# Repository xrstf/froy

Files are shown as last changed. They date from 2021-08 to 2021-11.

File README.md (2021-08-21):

# Frøy - ESP8266+BME Hygrometer

This repository contains the source code, schematics and everything else for my
personal fancy homegrown hygrometer (sensor that reports temperature, humidity and
pressure).

## Features

* push or pull mode
* supports BME280, BME680 and BMP280 chips
* programming via USB (only for indoor variant, others need a standalone USB->UART converter)
* webserver with Prometheus compatible `/metrics` endpoint
* reconfiguration via USB or WiFi (i.e. `curl -XPOST -d'{"new":"config"}' http://device/`)
* OTA pull support (Frøy pulls new firmware from a specified location)
* TLS support (single fingerprint only)
* relatively easy to solder by hand (nothing smaller than an 0805 package)

## Mode of Operation

Both indoor and outdoor versions can work in one of two modes:

* **Pull Mode** ("server mode") -- in this mode, Frøy is constantly running and connected
  to your WiFi. It provides an HTTP server and expects you to fetch the data whenever
  you need it (for example via Prometheus).
* **Push Mode** -- in this mode, Frøy will make a measurement, connect to WiFi, send out the
  data to a preconfigured URL and then go to sleep for a configurable amount of time. Rinse
  and repeat.

The advantage of the Pull Mode is that the interval can be centralled controlled (if you have
multiple devices). It also makes it easier to trigger an OTA, as Frøy is constantly listening
for requests.

The advantage of the Push Mode is that Frøy doesn't need any Firewall rules to be reachable
and it saves power (critical for the Outdoor version). Also, indoor versions in Pull Mode would
considerable heat up (an ESP8266 that is connected to WiFi can be 35-40°C) and skew the sensor
readings. So even for indoor versions it is advisable to use Push Mode instead.

While Frøy is not reachable in Push Mode (it never starts a webserver and you'd be pretty luck
to send a request to it the moment it wakes up and before it goes back to sleep), it is still
possible to reconfigurable Frøy remotely by putting the new configuration in the _response_ to
Frøy's push request.

## Flavors

Frøy currently comes in three flavors:

### Frøy Outdoor

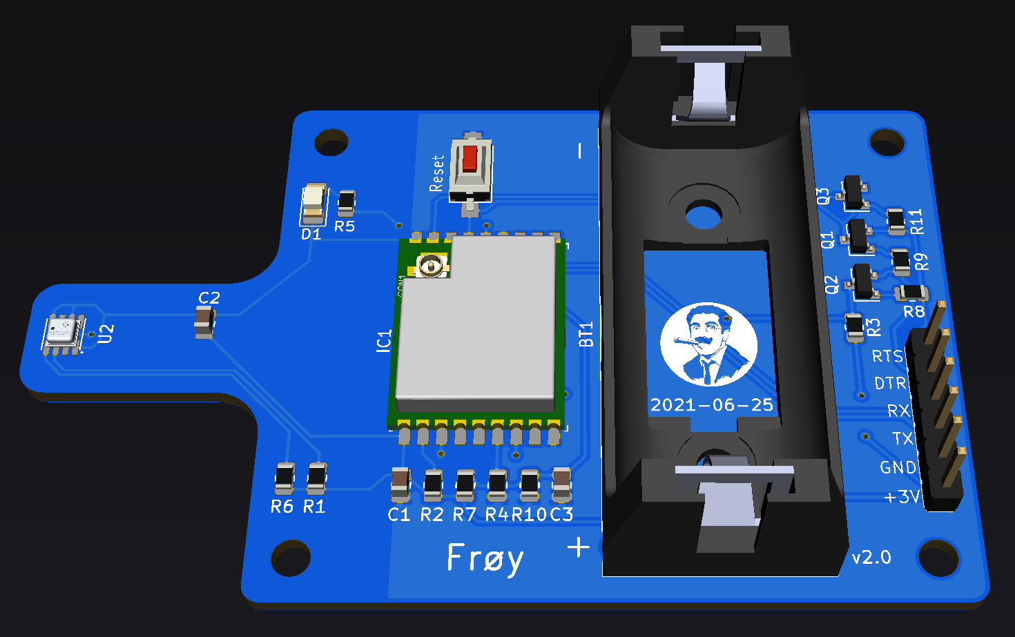
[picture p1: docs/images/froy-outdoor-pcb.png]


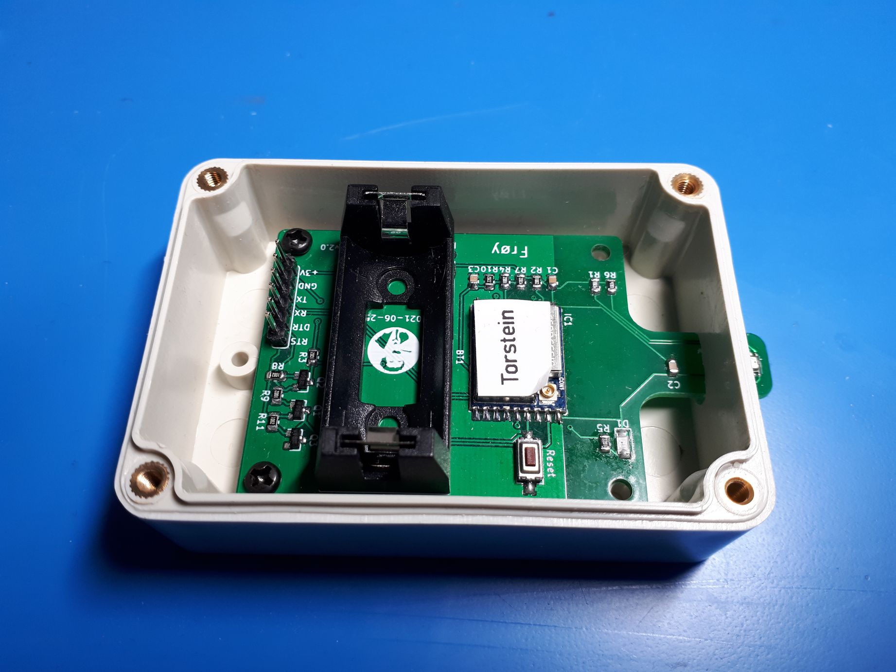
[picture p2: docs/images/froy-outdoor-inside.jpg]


This is the original project. It runs using a CR123 battery, which lasts roughly 3-5
months when reporting data every 15 minutes.

The case can be bought on Amazon: https://www.amazon.de/gp/product/B072M2JKGW/ -- I am not
aware of any alternative sources. In case the product disappears, I saved the schematics
in `docs/images/froy-outdoor-case-drawings.jpg`.

### Frøy Indoor

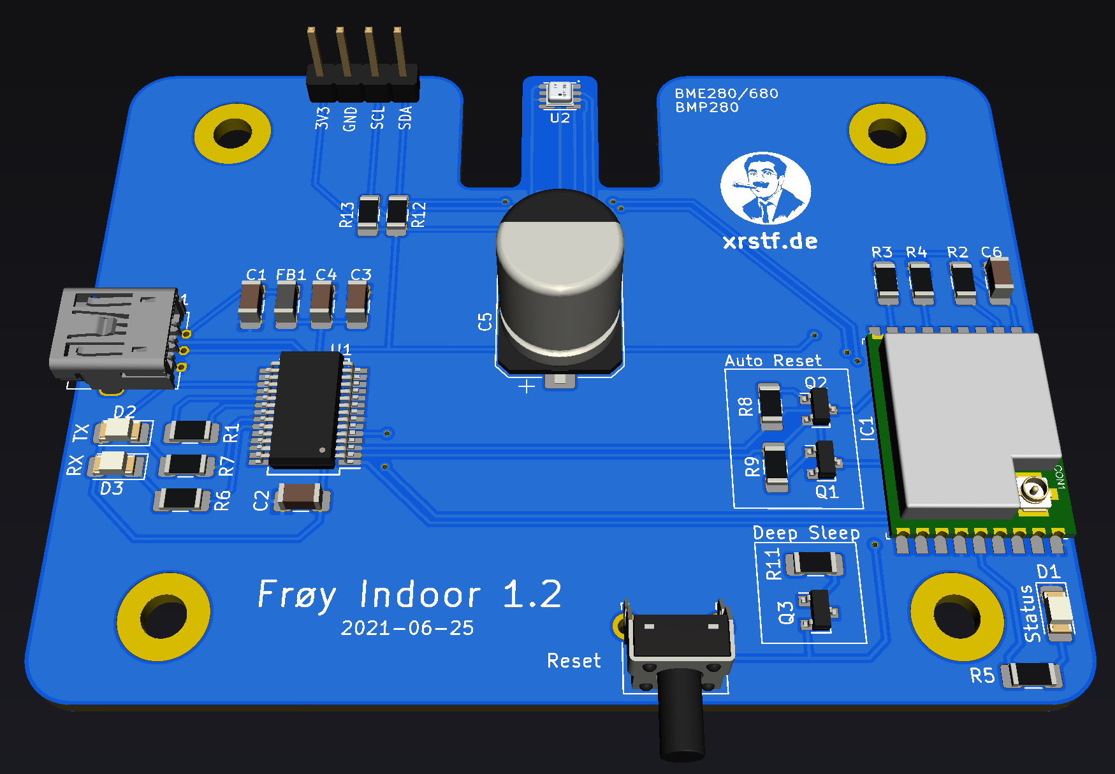
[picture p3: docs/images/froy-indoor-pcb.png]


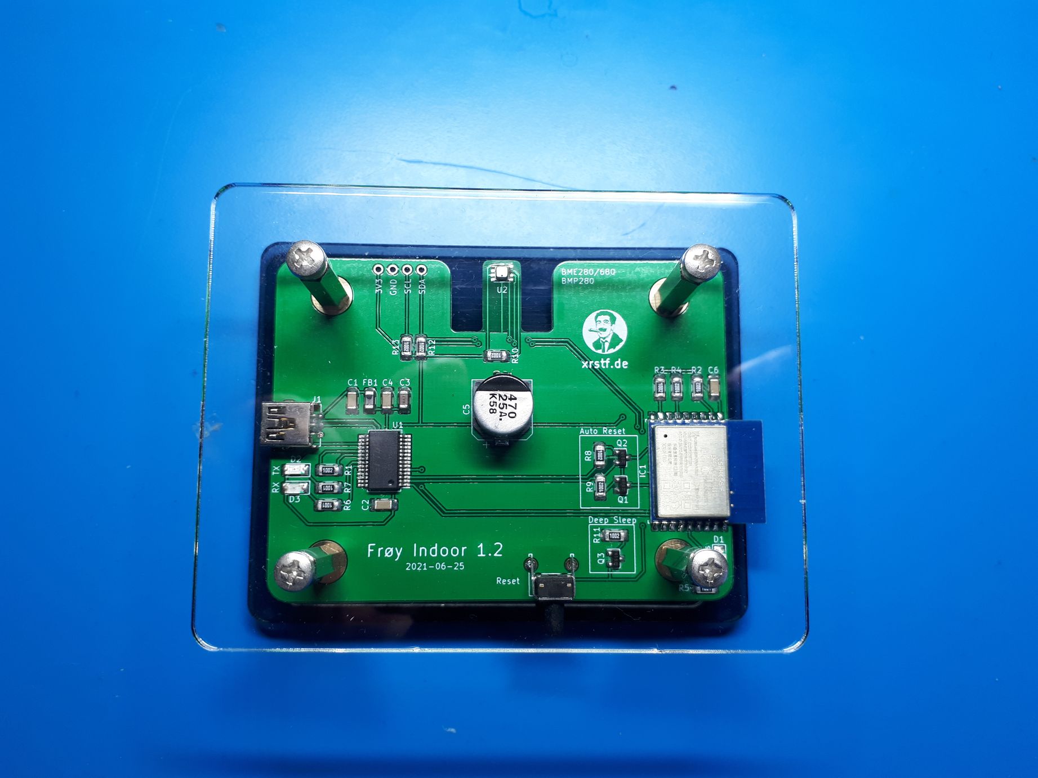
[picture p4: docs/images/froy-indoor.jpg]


This variant is powered by USB and suitable for indoor use.

### Froy ForMen

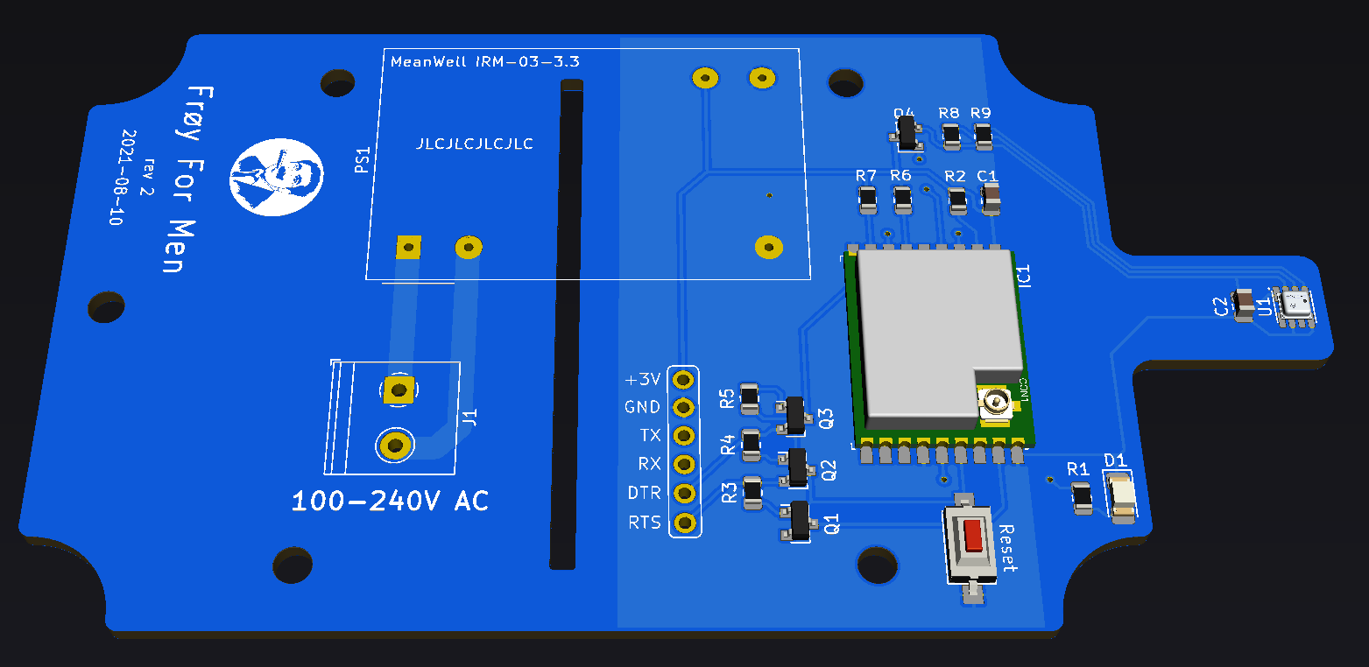
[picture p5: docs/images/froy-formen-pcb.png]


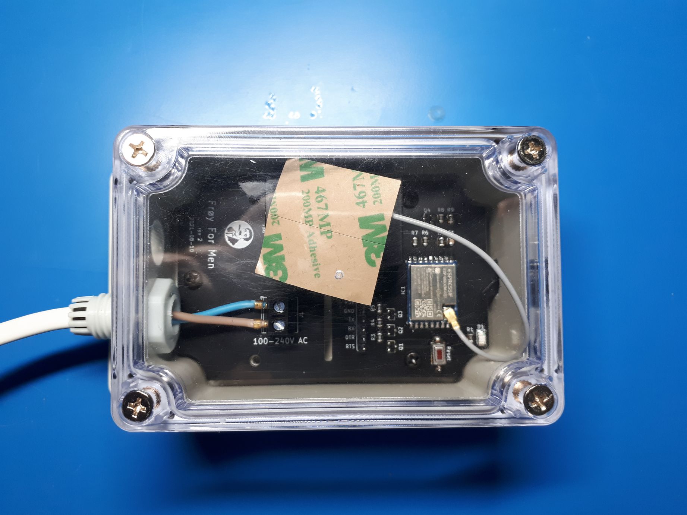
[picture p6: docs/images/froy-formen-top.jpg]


This variant is powered by mains voltage and is suitable for locations where changing
the battery regularly is not desirable.

The case can be bought on Amazon, for example https://www.amazon.de/gp/product/B07B9KY9X4/ --
alternatively search for "Snowsound case" on your favorite search engine.

---

Frøy was named after the character in the NRK series ["Norsemen"](https://tv.nrk.no/serie/vikingane).

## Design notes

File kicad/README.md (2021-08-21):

# KiCad Designs

These designs require that https://github.com/xrstf/kicad-library is set up in your
local KiCad 5 installation.

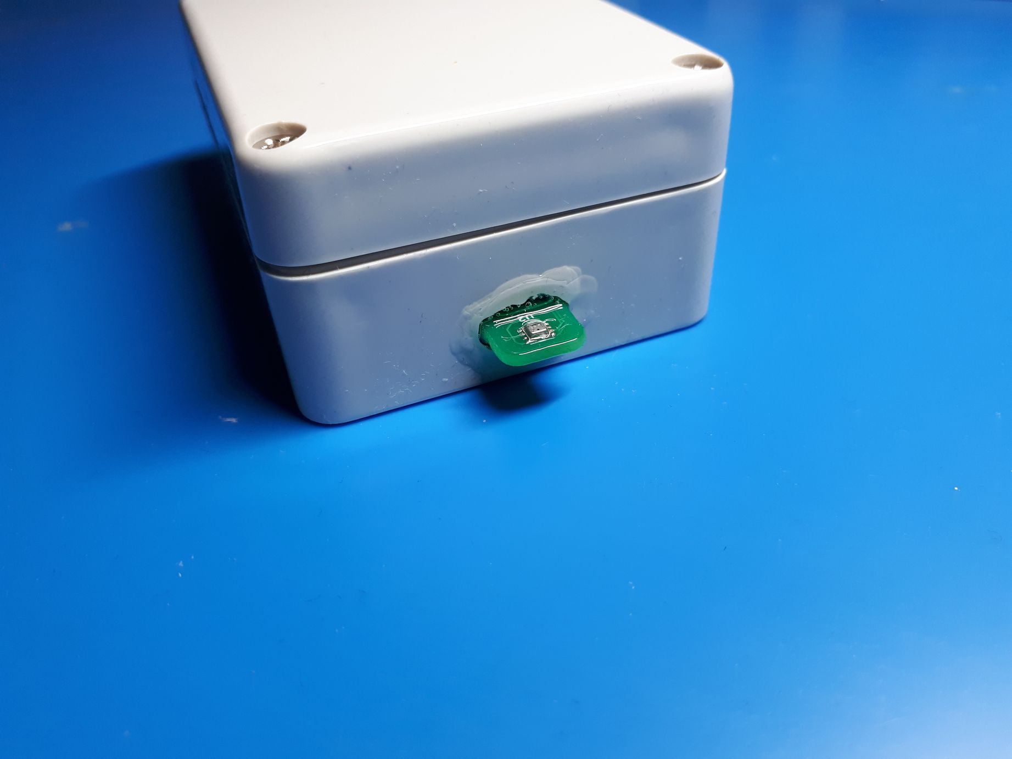
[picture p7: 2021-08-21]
docs/images/froy-outdoor-sensor.jpg

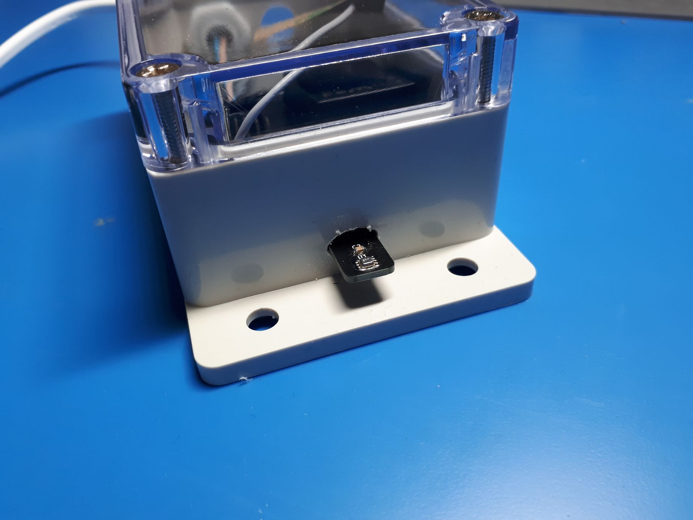
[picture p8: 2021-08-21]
docs/images/froy-formen-sensor.jpg

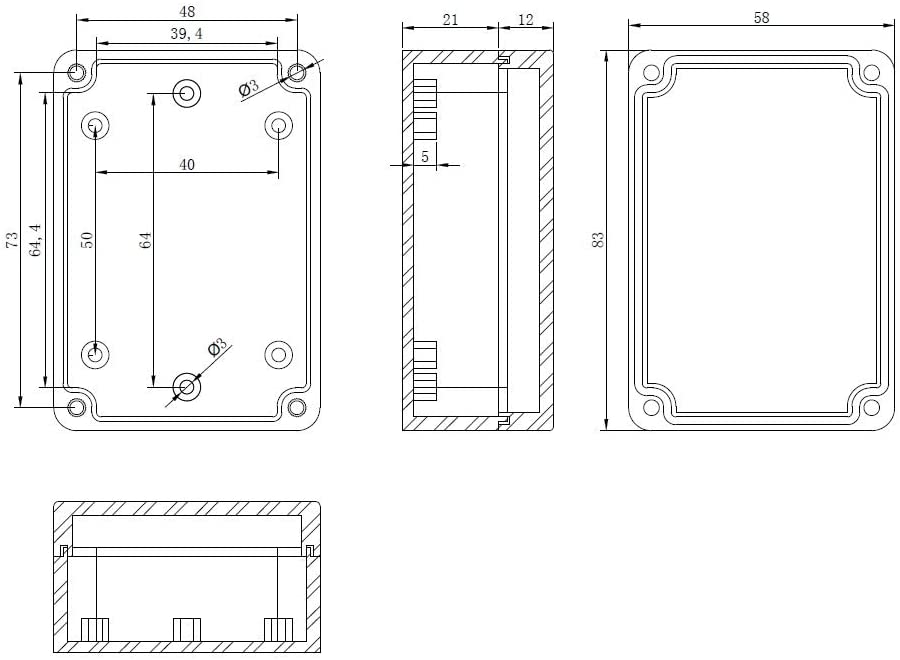
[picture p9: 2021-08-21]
docs/images/froy-outdoor-case-drawings.jpg

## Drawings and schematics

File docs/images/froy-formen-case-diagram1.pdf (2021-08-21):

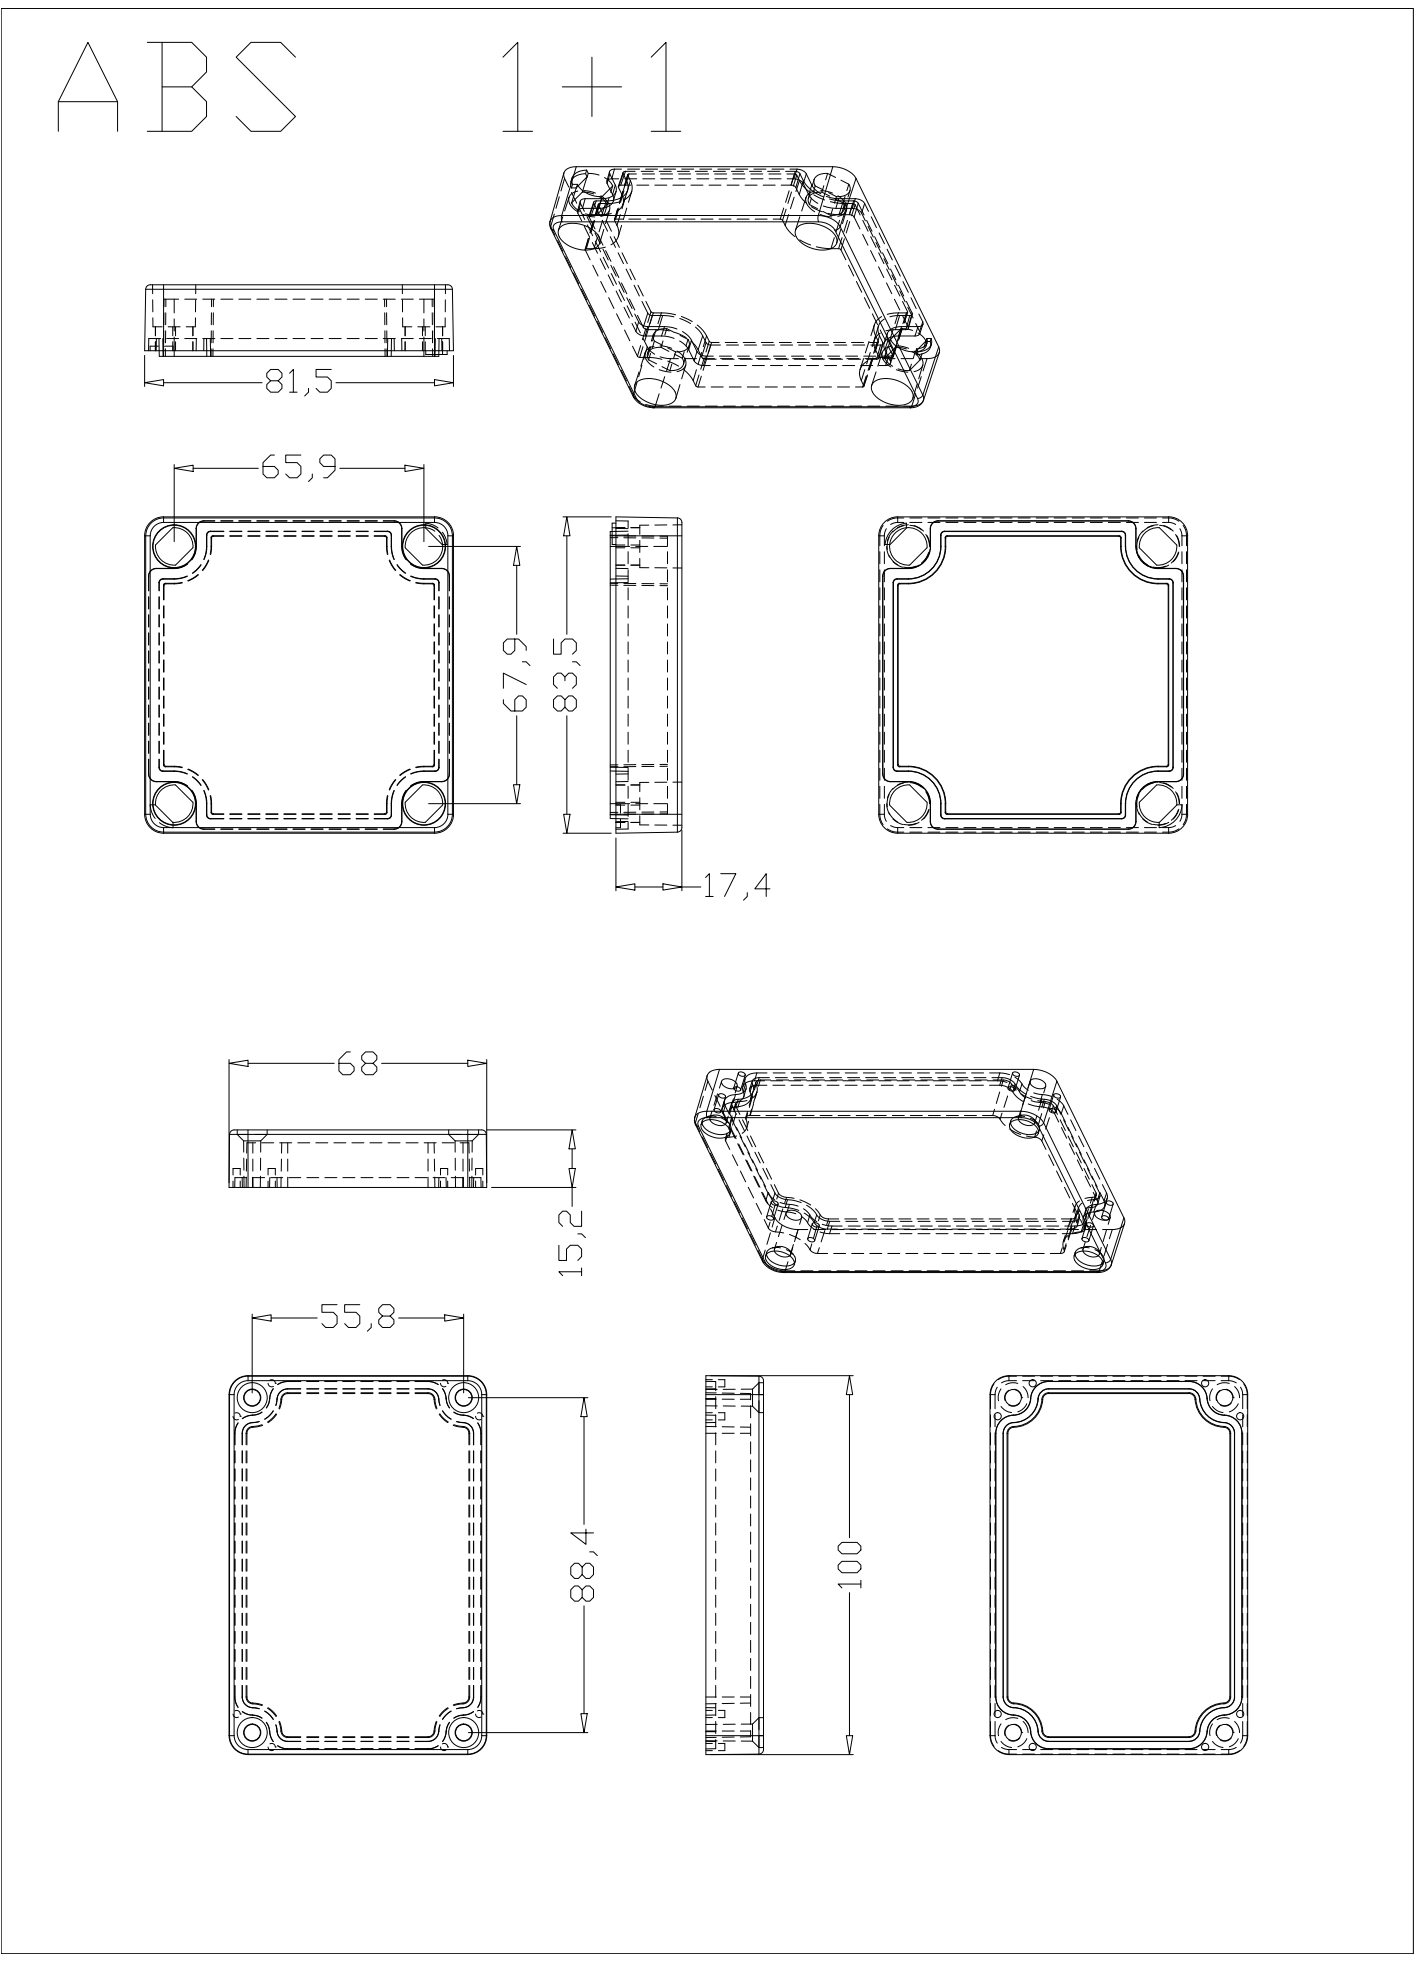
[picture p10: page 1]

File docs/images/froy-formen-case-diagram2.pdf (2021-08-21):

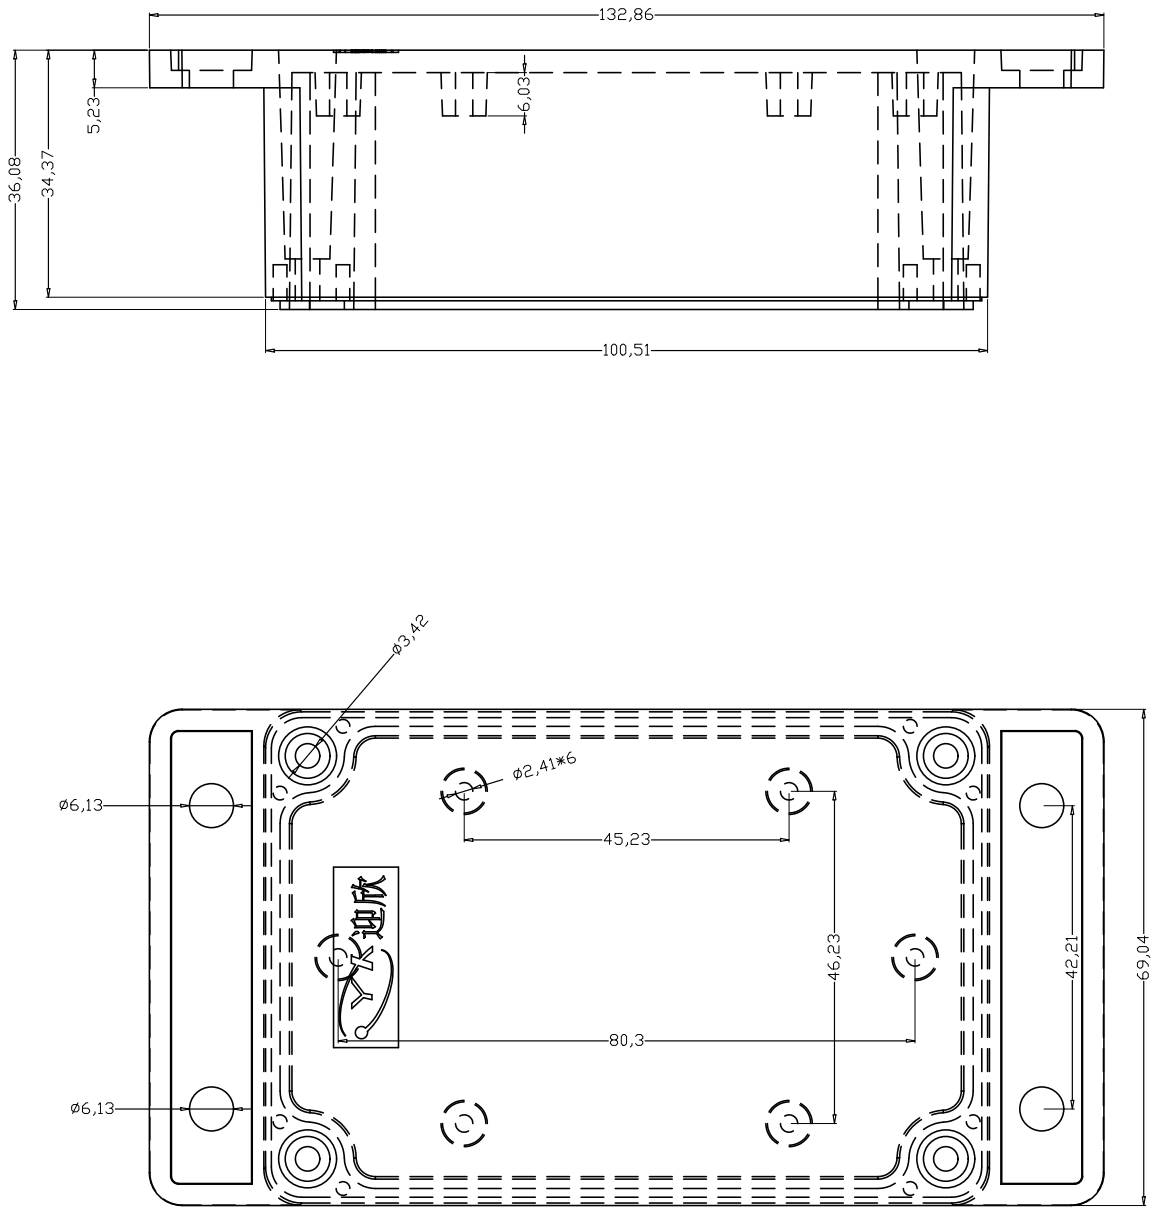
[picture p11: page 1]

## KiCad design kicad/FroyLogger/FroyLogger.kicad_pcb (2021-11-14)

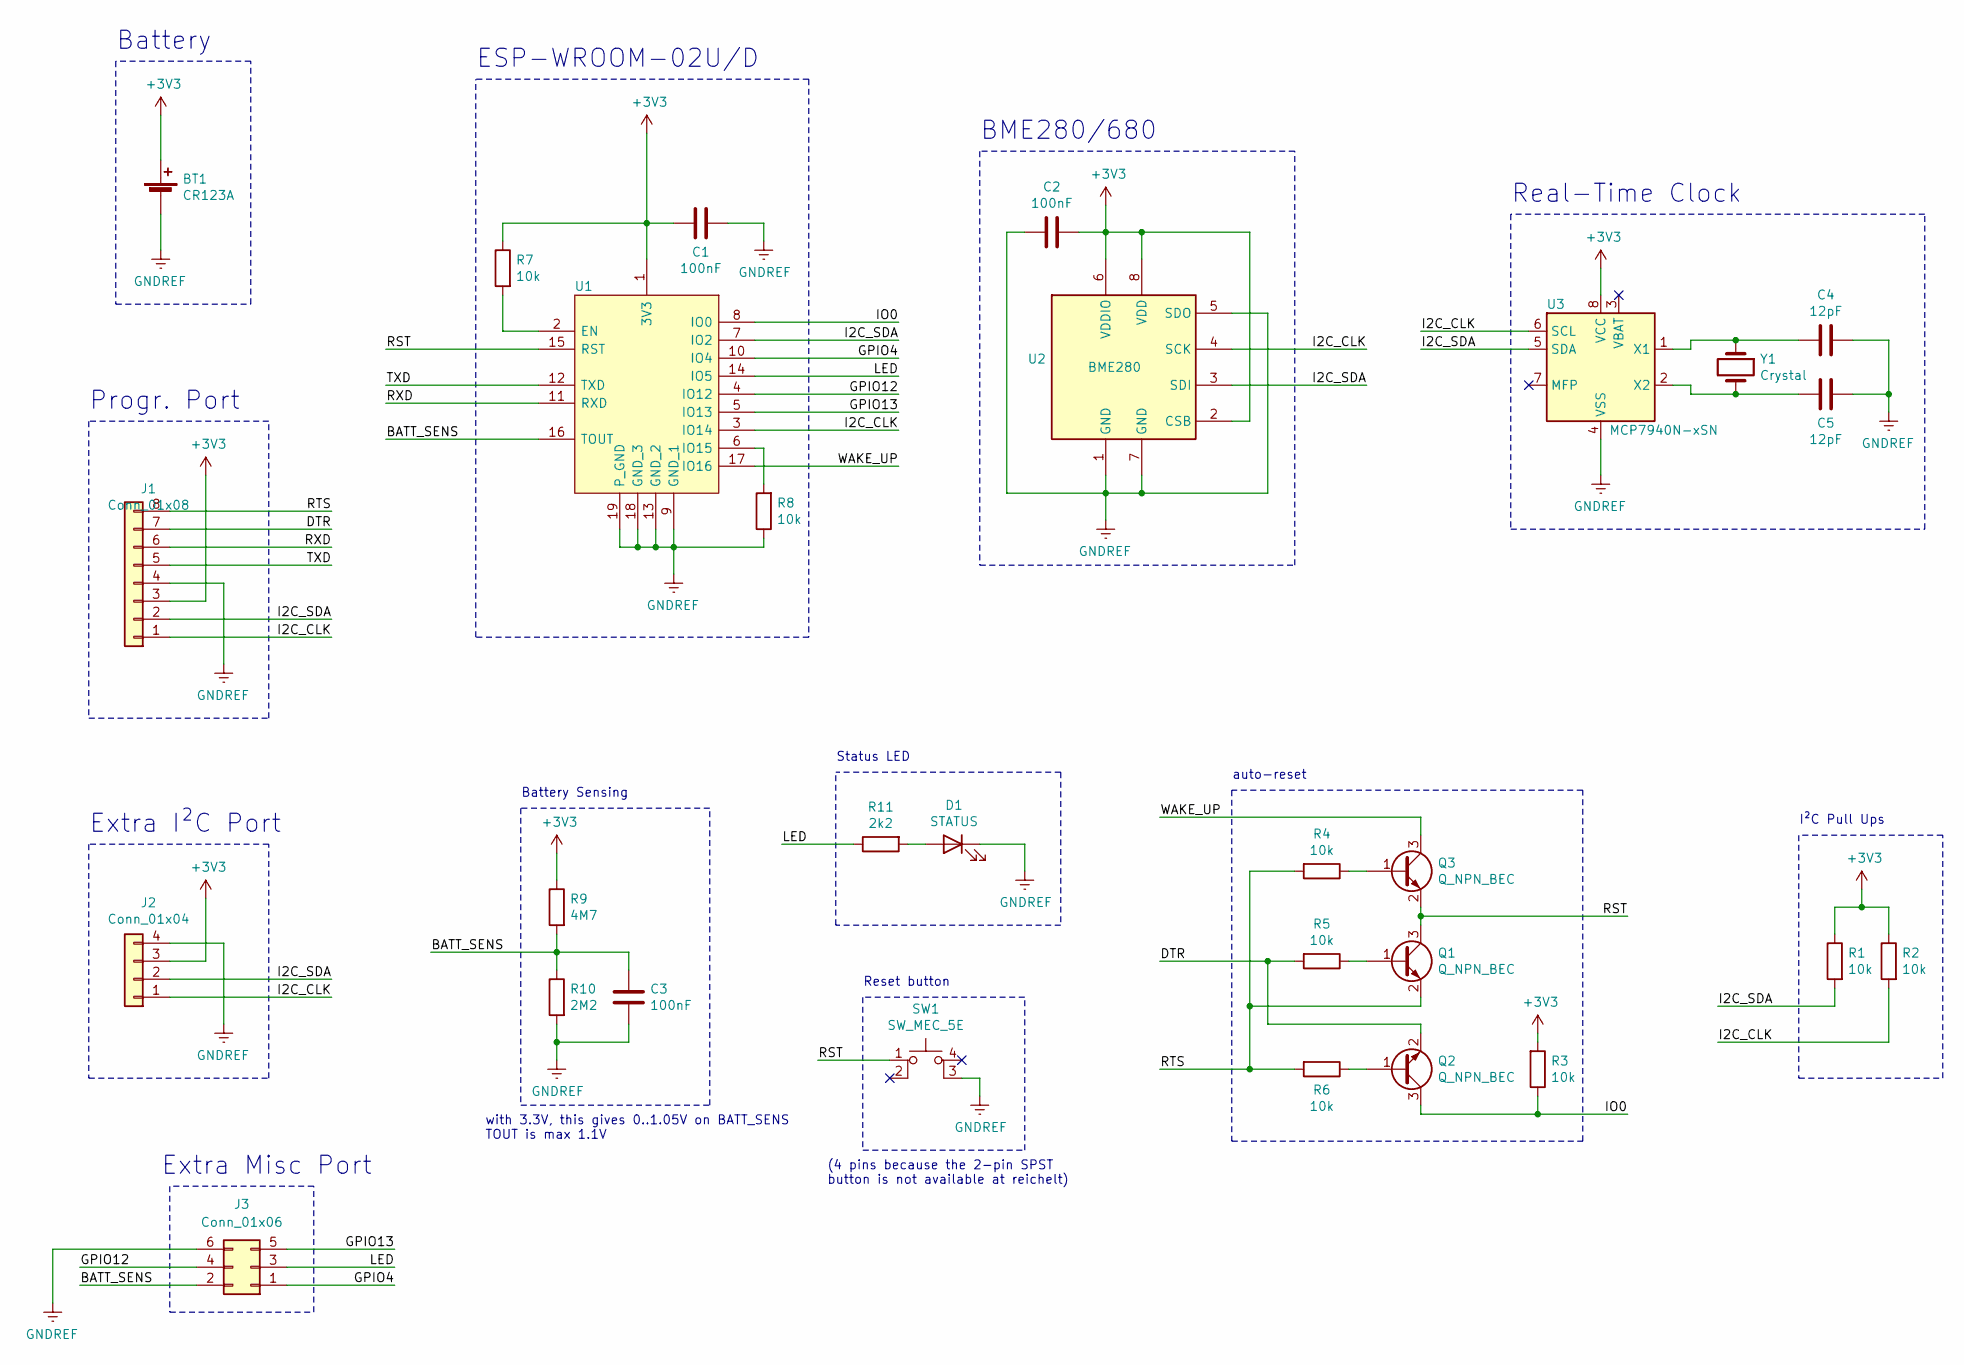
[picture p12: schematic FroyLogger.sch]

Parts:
BT1: CR123A; CR123A_Holder_ThroughHole
C1, C2, C3: 100nF; C_0805_2012Metric
C4, C5: 12pF; C_0805_2012Metric
D1: STATUS; LED_0805_2012Metric
J1: Conn_01x08; PinHeader_1x08_P2.54mm_Vertical
J2: Conn_01x04; PinHeader_1x04_P2.54mm_Vertical
J3: Conn_01x06; PinHeader_2x03_P2.54mm_Vertical
Q1, Q2, Q3: Q_NPN_BEC; SOT-23
R1, R2, R3, R4, R5, R6, R7, R8: 10k; R_0805_2012Metric
R9: 4M7; R_0805_2012Metric
R10: 2M2; R_0805_2012Metric
R11: 2k2; R_0805_2012Metric
SW1: SW_MEC_5E; SW_SPST_Omron_B3FS-100xP
U1: ESP-WROOM-02U__4MB_; ESP-WROOM-02U
U2: BME280; BME280_680_BMP280
U3: MCP7940N-xSN; SOIC-8_3.9x4.9mm_P1.27mm
Y1: Crystal; Crystal_SMD_SeikoEpson_MC405-2Pin_9.6x4.1mm

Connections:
+3V3: BT1.1 (+), C1.1, C2.2, J1.3, J2.3, R1.1, R2.1, R3.2, R7.1, R9.1, U1.1 (3V3), U2.2 (CSB), U2.6 (VDDIO), U2.8 (VDD), U3.8 (VCC)
/BATT_SENS: C3.2, J3.2, R9.2, R10.1, U1.16 (TOUT)
/DTR: J1.7, Q2.2 (E), R5.2
/GPIO4: J3.1, U1.10 (IO4)
/GPIO12: J3.4, U1.4 (IO12)
/GPIO13: J3.5, U1.5 (IO13)
/I2C_CLK: J1.1, J2.1, R2.2, U1.3 (IO14), U2.4 (SCK), U3.6 (SCL)
/I2C_SDA: J1.2, J2.2, R1.2, U1.7 (IO2), U2.3 (SDI), U3.5 (SDA)
/IO0: Q2.3 (C), R3.1, U1.8 (IO0)
/LED: J3.3, R11.1, U1.14 (IO5)
/RST: Q1.3 (C), Q3.2 (E), SW1.1, U1.15 (RST)
/RTS: J1.8, Q1.2 (E), R4.2, R6.2
/RXD: J1.6, U1.11 (RXD)
/TXD: J1.5, U1.12 (TXD)
/WAKE_UP: Q3.3 (C), U1.17 (IO16)
GNDREF: BT1.2 (-), C1.2, C2.1, C3.1, C4.2, C5.2, D1.1 (K), J1.4, J2.4, J3.6, R8.1, R10.2, SW1.3 (K), U1.9 (GND_1), U1.13 (GND_2), U1.18 (GND_3), U1.19 (P_GND), U2.1 (GND), U2.5 (SDO), U2.7 (GND), U3.4 (VSS)
unnamed: C4.1, U3.1 (X1), Y1.1
unnamed: C5.1, U3.2 (X2), Y1.2
unnamed: D1.2 (A), R11.2
unnamed: Q1.1 (B), R5.1
unnamed: Q2.1 (B), R6.1
unnamed: Q3.1 (B), R4.1
unnamed: R7.2, U1.2 (EN)
unnamed: R8.2, U1.6 (IO15)

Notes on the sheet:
Status LED
auto-reset
ESP-WROOM-02U/D
Reset button
BME280/680
I²C Pull Ups
Battery
Progr. Port
Battery Sensing
with 3.3V, this gives 0..1.05V on BATT_SENS TOUT is max 1.1V
(4 pins because the 2-pin SPST button is not available at reichelt)
Real-Time Clock
Extra I²C Port
Extra Misc Port

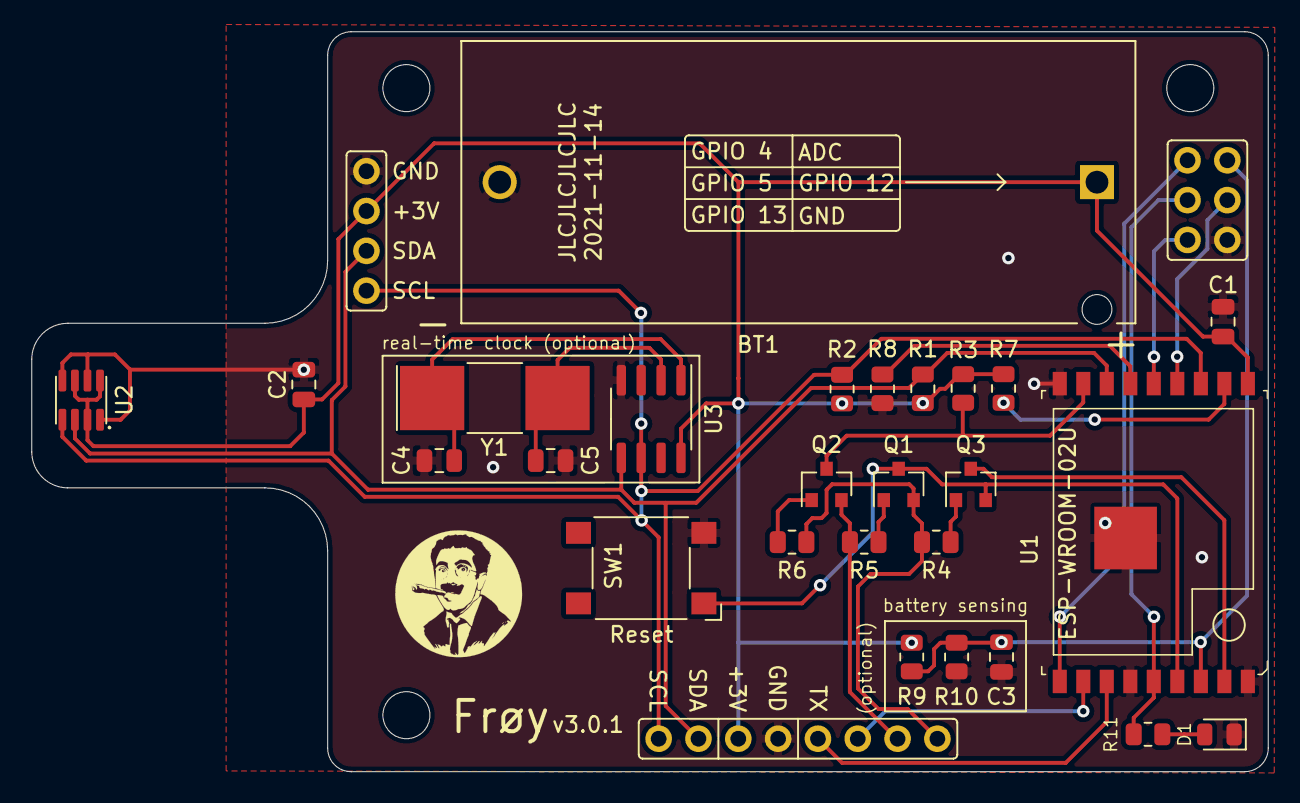
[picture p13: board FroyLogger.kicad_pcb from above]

Board: 2 copper layers, 78.9 x 47.2 mm, 33 parts (0 on the bottom side), 24 nets.

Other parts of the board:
G1: LOGO; groucho
H1: NW; MountingHole_3mm
H2: NE; MountingHole_3mm
H4: SW; MountingHole_3mm

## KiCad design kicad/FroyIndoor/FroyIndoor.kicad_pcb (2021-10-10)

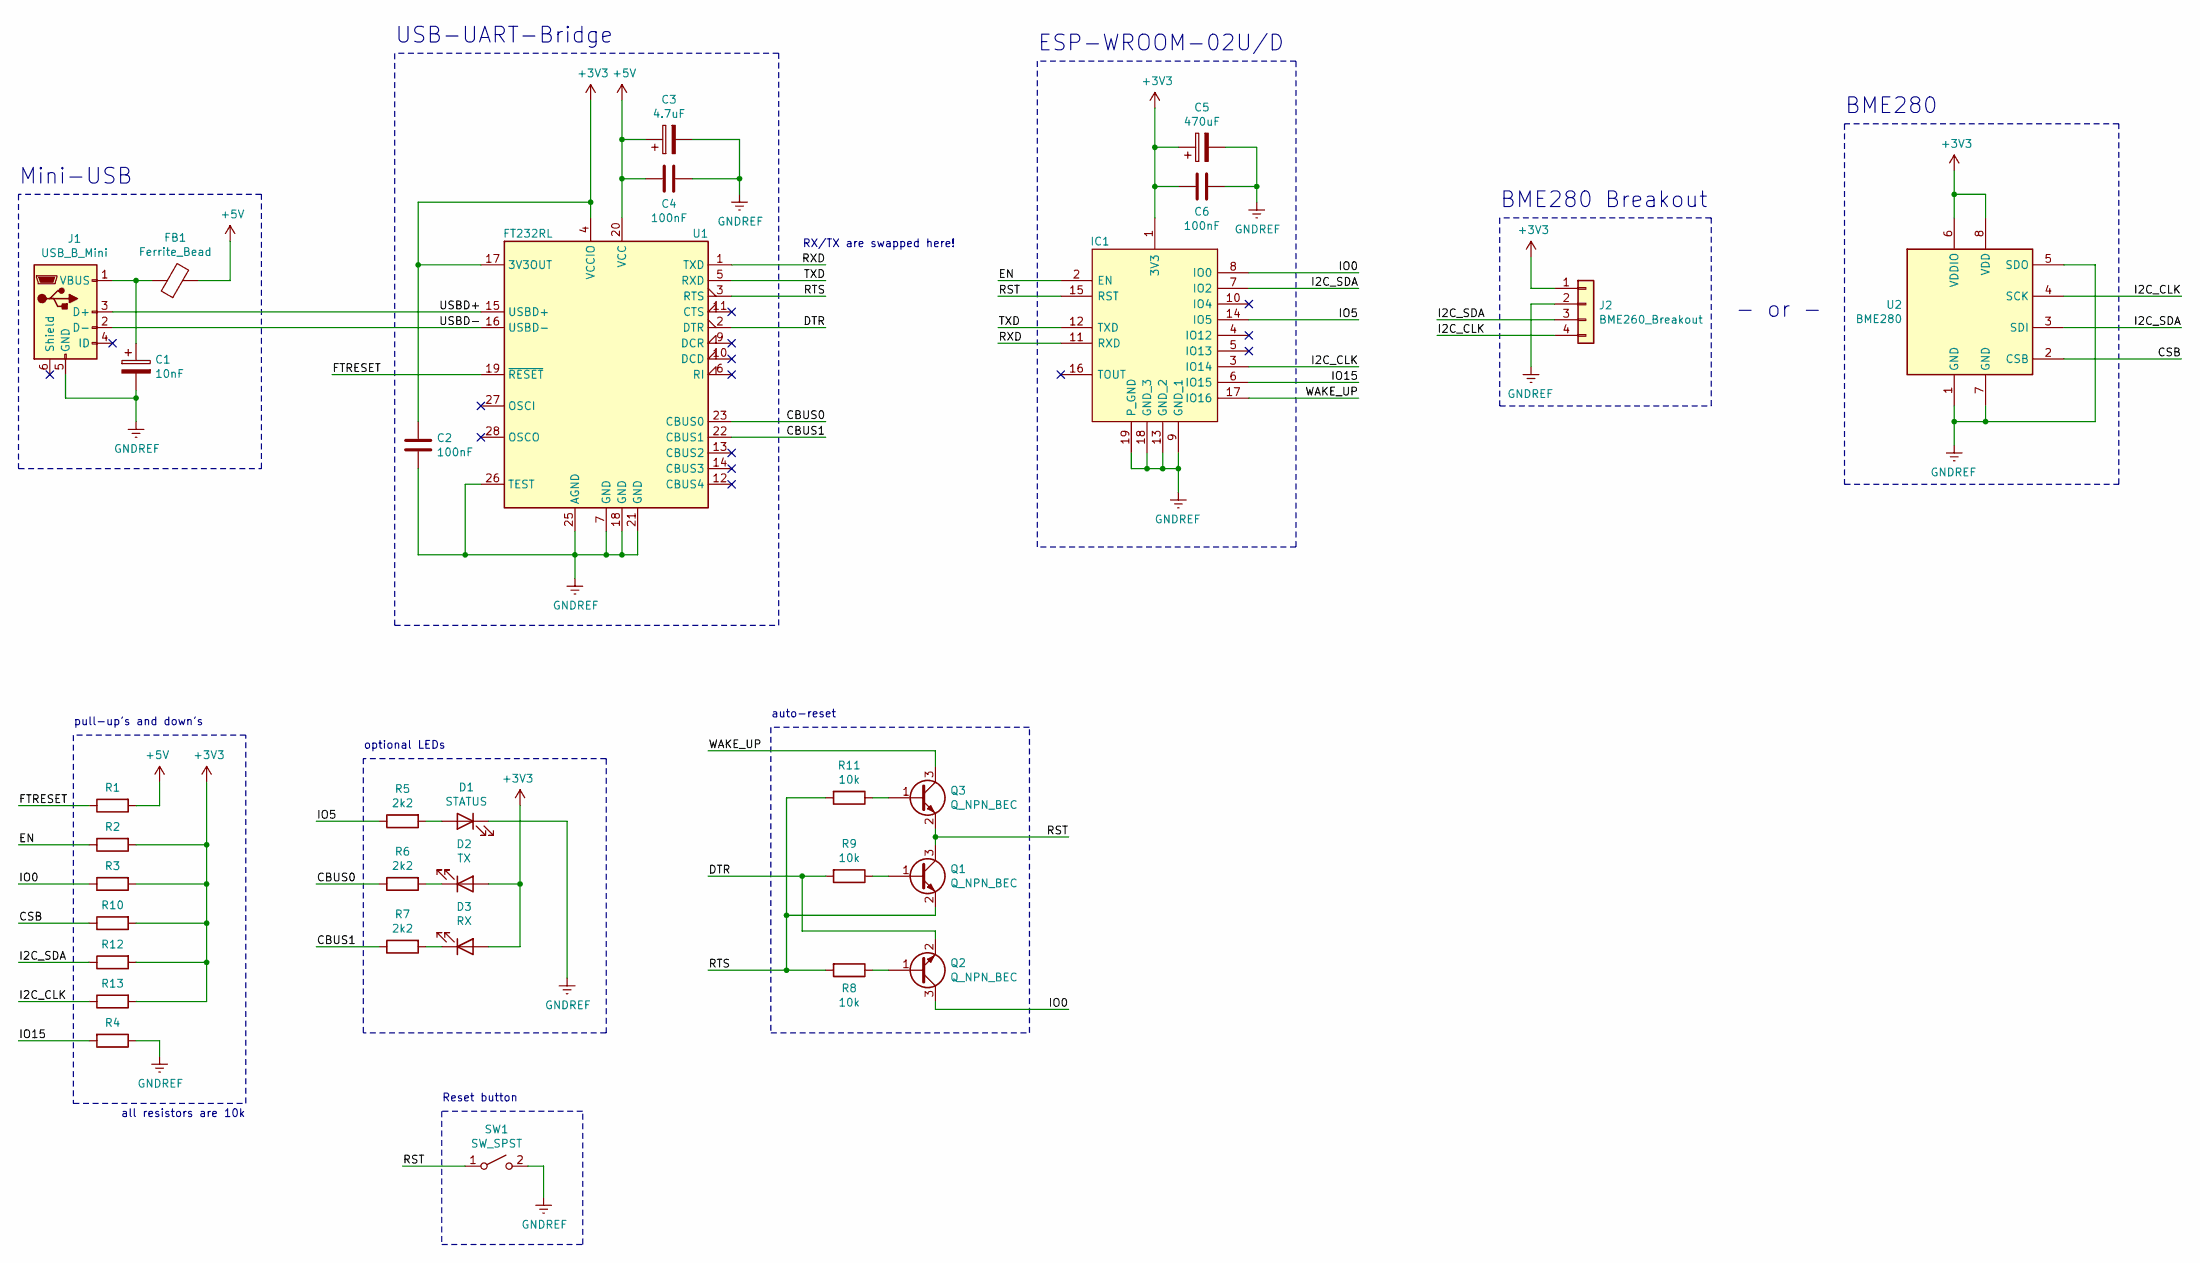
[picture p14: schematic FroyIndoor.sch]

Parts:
C1: 10nF; C_1206_3216Metric_Pad1.42x1.75mm_HandSolder
C2, C4, C6: 100nF; C_1206_3216Metric_Pad1.42x1.75mm_HandSolder
C3: 4.7uF; C_1206_3216Metric_Pad1.42x1.75mm_HandSolder
C5: 470uF; CP_Elec_10x12.5
D1: STATUS; LED_1206_3216Metric_Pad1.42x1.75mm_HandSolder
D2: TX; LED_1206_3216Metric_Pad1.42x1.75mm_HandSolder
D3: RX; LED_1206_3216Metric_Pad1.42x1.75mm_HandSolder
FB1: Ferrite_Bead; L_1206_3216Metric_Pad1.42x1.75mm_HandSolder
IC1: ESP-WROOM-02U__4MB_; ESP-WROOM-02U
J1: USB_B_Mini; USB_BWM_MIniUSB_THT_reichelt
J2: BME260_Breakout; PinHeader_1x04_P2.54mm_Vertical
Q1, Q2, Q3: Q_NPN_BEC; SOT-23
R1, R2, R3, R4, R8, R9, R10, R11, R12, R13: 10k; R_1206_3216Metric_Pad1.42x1.75mm_HandSolder
R5, R6, R7: 2k2; R_1206_3216Metric_Pad1.42x1.75mm_HandSolder
SW1: SW_SPST; SW_Tactile_SPST_Angled_PTS645Vx83-2LFS
U1: FT232RL; SSOP-28_5.3x10.2mm_P0.65mm
U2: BME280; BME280_680_BMP280

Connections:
+3V3: C2.1, C5.1, C6.1, D2.2 (A), D3.2 (A), IC1.1 (3V3), J2.1, R2.2, R3.2, R10.2, R12.2, R13.2, U1.4 (VCCIO), U1.17 (3V3OUT), U2.6 (VDDIO), U2.8 (VDD)
+5V: C3.1, C4.1, FB1.2, R1.2, U1.20 (VCC)
/CBUS0: R6.1, U1.23 (CBUS0)
/CBUS1: R7.1, U1.22 (CBUS1)
/CSB: R10.1, U2.2 (CSB)
/DTR: Q2.2 (E), R9.2, U1.2 (DTR)
/EN: IC1.2 (EN), R2.1
/FTRESET: R1.1, U1.19 (~RESET~)
/I2C_CLK: IC1.3 (IO14), J2.4, R13.1, U2.4 (SCK)
/I2C_SDA: IC1.7 (IO2), J2.3, R12.1, U2.3 (SDI)
/IO0: IC1.8 (IO0), Q2.3 (C), R3.1
/IO5: IC1.14 (IO5), R5.1
/IO15: IC1.6 (IO15), R4.2
/RST: IC1.15 (RST), Q1.3 (C), Q3.2 (E), SW1.1 (A)
/RTS: Q1.2 (E), R8.2, R11.2, U1.3 (RTS)
/RXD: IC1.11 (RXD), U1.1 (TXD)
/TXD: IC1.12 (TXD), U1.5 (RXD)
/USBD+: J1.3 (D+), U1.15 (USBD+)
/USBD-: J1.2 (D-), U1.16 (USBD-)
/WAKE_UP: IC1.17 (IO16), Q3.3 (C)
GNDREF: C1.2, C2.2, C3.2, C4.2, C5.2, C6.2, D1.1 (K), IC1.9 (GND_1), IC1.13 (GND_2), IC1.18 (GND_3), IC1.19 (P_GND), J1.5 (GND), J2.2, R4.1, SW1.2 (B), U1.7 (GND), U1.18 (GND), U1.21 (GND), U1.25 (AGND), U1.26 (TEST), U2.1 (GND), U2.5 (SDO), U2.7 (GND)
unnamed: C1.1, FB1.1, J1.1 (VBUS)
unnamed: D1.2 (A), R5.2
unnamed: D2.1 (K), R6.2
unnamed: D3.1 (K), R7.2
unnamed: Q1.1 (B), R9.1
unnamed: Q2.1 (B), R8.1
unnamed: Q3.1 (B), R11.1

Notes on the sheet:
USB-UART-Bridge
Mini-USB
optional LEDs
auto-reset
pull-up's and down's
all resistors are 10k
RX/TX are swapped here!
ESP-WROOM-02U/D
BME280 Breakout
Reset button
BME280
- or -

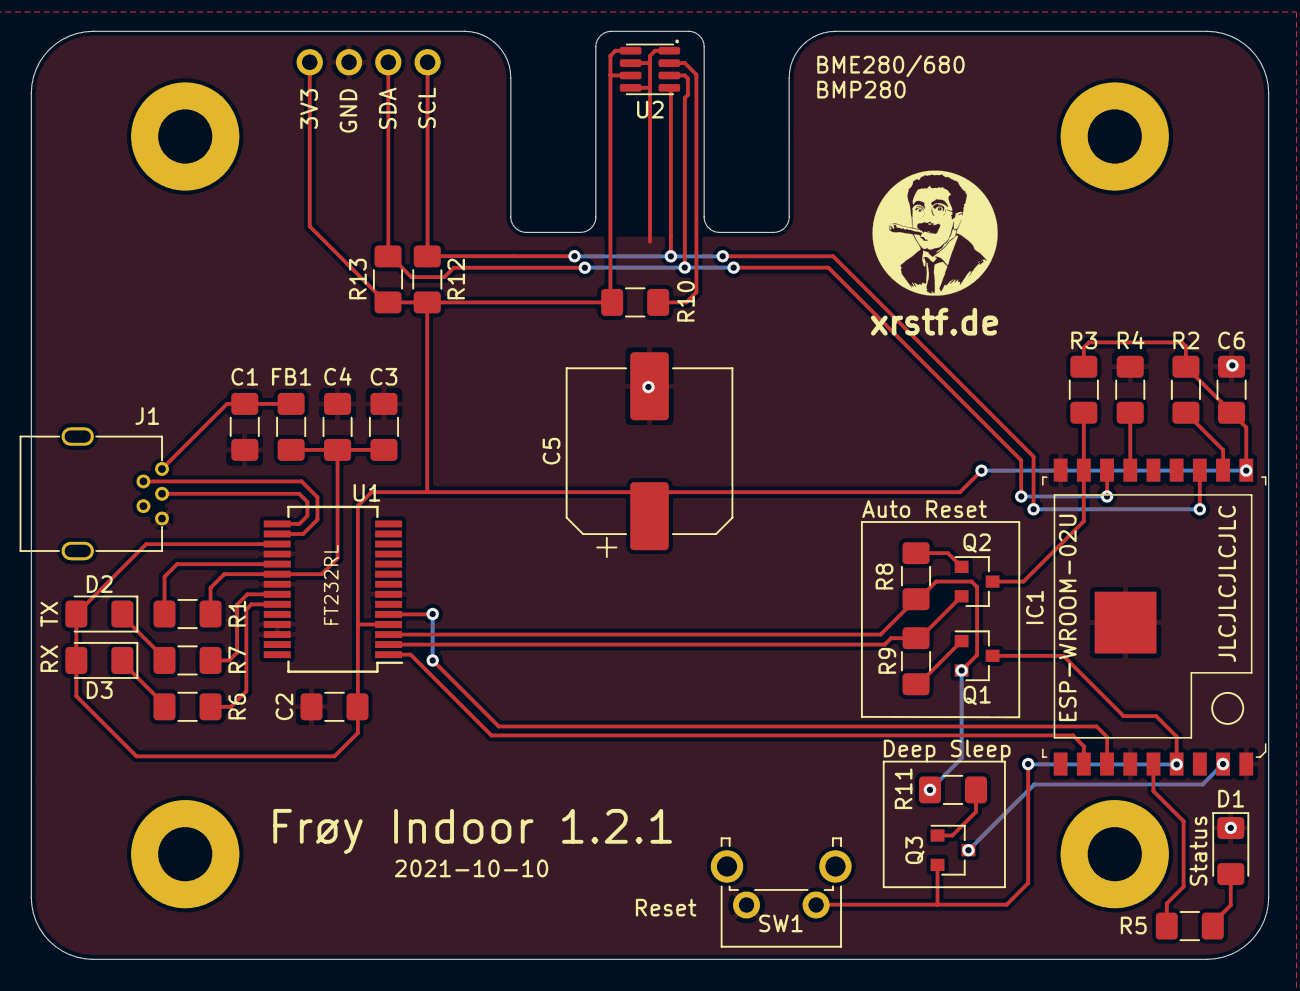
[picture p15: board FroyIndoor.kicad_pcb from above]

Board: 2 copper layers, 80.0 x 60.0 mm, 32 parts (0 on the bottom side), 28 nets.

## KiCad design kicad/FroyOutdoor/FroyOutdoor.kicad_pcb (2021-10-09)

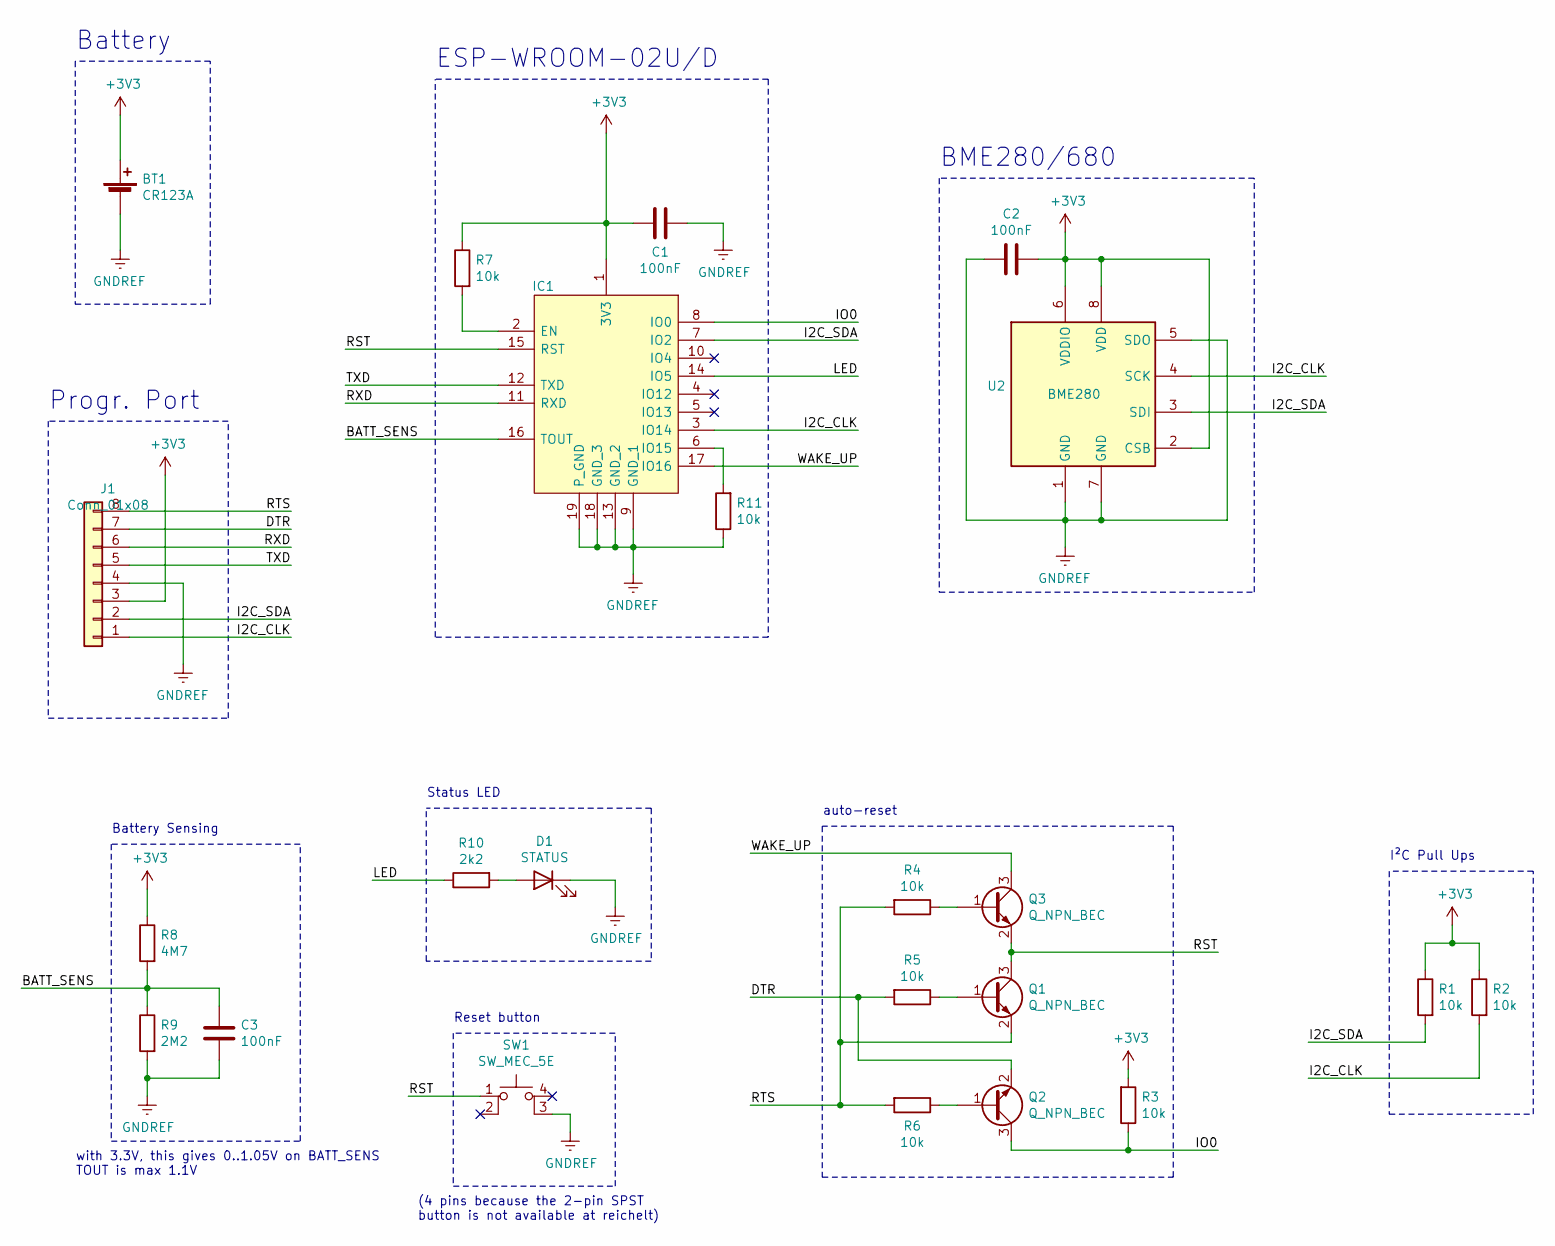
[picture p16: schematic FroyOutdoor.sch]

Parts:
BT1: CR123A; CR123A_Holder_ThroughHole
C1, C2, C3: 100nF; C_0805_2012Metric
D1: STATUS; LED_0805_2012Metric
IC1: ESP-WROOM-02U__4MB_; ESP-WROOM-02U
J1: Conn_01x08; PinHeader_1x08_P2.54mm_Vertical
Q1, Q2, Q3: Q_NPN_BEC; SOT-23
R1, R2, R3, R4, R5, R6, R7, R11: 10k; R_0805_2012Metric
R8: 4M7; R_0805_2012Metric
R9: 2M2; R_0805_2012Metric
R10: 2k2; R_0805_2012Metric
SW1: SW_MEC_5E; SW_SPST_Omron_B3FS-100xP
U2: BME280; BME280_680_BMP280

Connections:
+3V3: BT1.1 (+), C1.1, C2.2, IC1.1 (3V3), J1.3, R1.1, R2.1, R3.2, R7.1, R8.1, U2.2 (CSB), U2.6 (VDDIO), U2.8 (VDD)
/BATT_SENS: C3.2, IC1.16 (TOUT), R8.2, R9.1
/DTR: J1.7, Q2.2 (E), R5.2
/I2C_CLK: IC1.3 (IO14), J1.1, R2.2, U2.4 (SCK)
/I2C_SDA: IC1.7 (IO2), J1.2, R1.2, U2.3 (SDI)
/IO0: IC1.8 (IO0), Q2.3 (C), R3.1
/LED: IC1.14 (IO5), R10.1
/RST: IC1.15 (RST), Q1.3 (C), Q3.2 (E), SW1.1
/RTS: J1.8, Q1.2 (E), R4.2, R6.2
/RXD: IC1.11 (RXD), J1.6
/TXD: IC1.12 (TXD), J1.5
/WAKE_UP: IC1.17 (IO16), Q3.3 (C)
GNDREF: BT1.2 (-), C1.2, C2.1, C3.1, D1.1 (K), IC1.9 (GND_1), IC1.13 (GND_2), IC1.18 (GND_3), IC1.19 (P_GND), J1.4, R9.2, R11.1, SW1.3 (K), U2.1 (GND), U2.5 (SDO), U2.7 (GND)
unnamed: D1.2 (A), R10.2
unnamed: IC1.2 (EN), R7.2
unnamed: IC1.6 (IO15), R11.2
unnamed: Q1.1 (B), R5.1
unnamed: Q2.1 (B), R6.1
unnamed: Q3.1 (B), R4.1

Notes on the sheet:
Status LED
auto-reset
ESP-WROOM-02U/D
Reset button
BME280/680
I²C Pull Ups
Battery
Progr. Port
Battery Sensing
with 3.3V, this gives 0..1.05V on BATT_SENS TOUT is max 1.1V
(4 pins because the 2-pin SPST button is not available at reichelt)

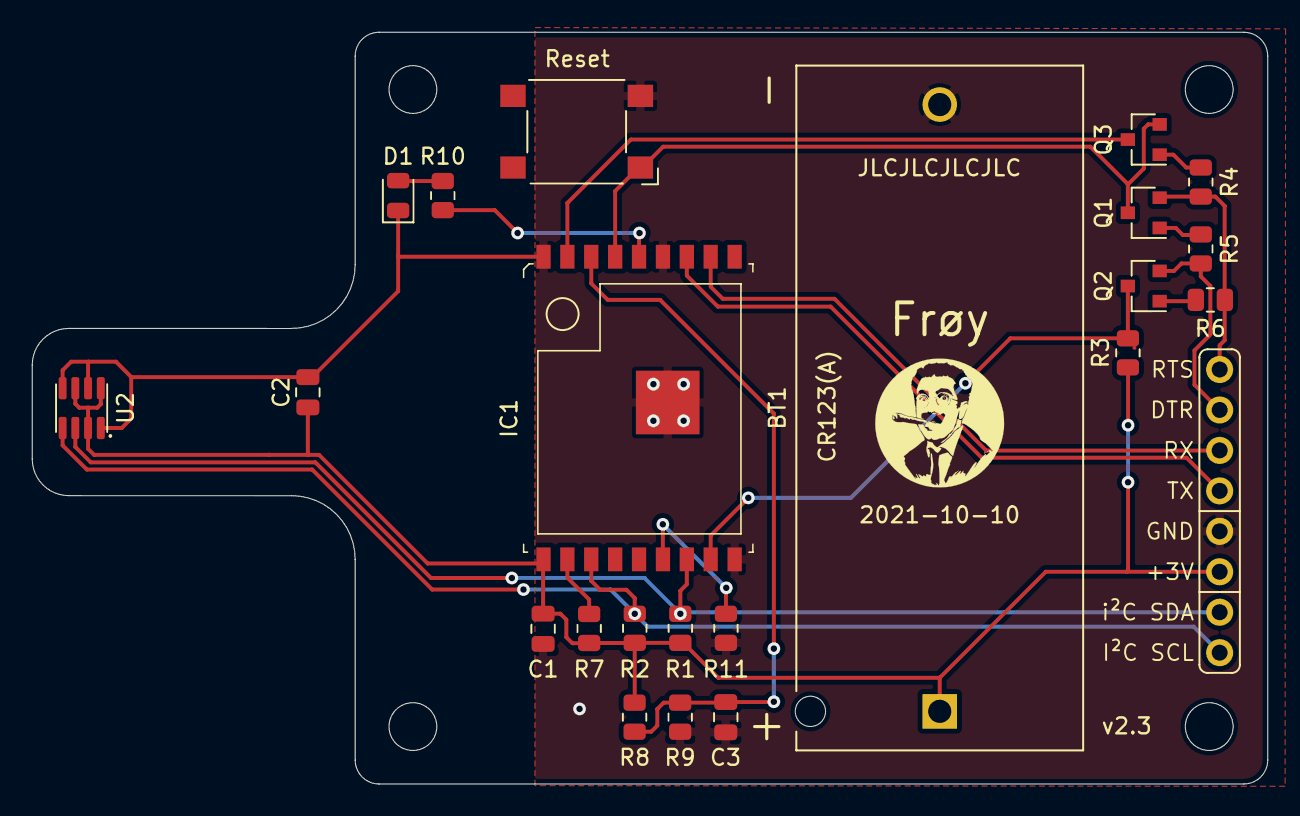
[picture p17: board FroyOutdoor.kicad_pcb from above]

Board: 2 copper layers, 77.6 x 47.2 mm, 27 parts (0 on the bottom side), 19 nets.

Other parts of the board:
H1: NW; MountingHole_3mm
H2: NE; MountingHole_3mm
H3: SE; MountingHole_3mm
H4: SW; MountingHole_3mm

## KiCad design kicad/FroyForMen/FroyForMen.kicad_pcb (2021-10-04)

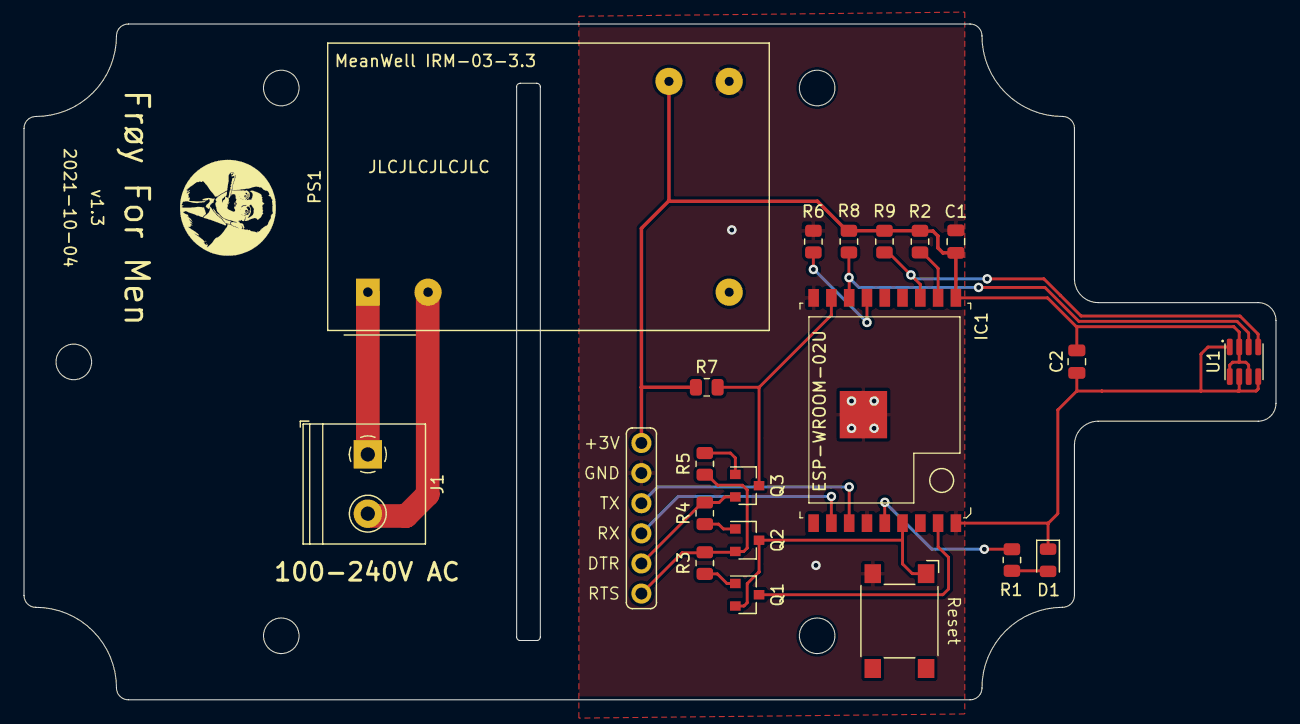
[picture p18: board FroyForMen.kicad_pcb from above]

Board: 2 copper layers, 105.6 x 57.0 mm, 26 parts (0 on the bottom side), 20 nets.

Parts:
C1, C2: 100nF; C_0805_2012Metric
D1: STATUS; LED_0805_2012Metric
H1: NW; MountingHole_3mm
H4, H4#2, H4#3, H4#4: SW; MountingHole_3mm
IC1: ESP-WROOM-02U__4MB_; ESP-WROOM-02U
J1: Screw_Terminal_01x02; TerminalBlock_Philmore_TB132_1x02_P5.00mm_Horizontal
J2: Conn_01x06; PinHeader_1x06_P2.54mm_Vertical
PS1: IRM-03-3.3; Converter_ACDC_MeanWell_IRM-03-xx_THT
Q1, Q2, Q3: Q_NPN_BEC; SOT-23
R1: 2k2; R_0805_2012Metric
R2, R3, R4, R5, R6, R7, R8, R9: 10k; R_0805_2012Metric
SW1: SW_MEC_5E; SW_SPST_Omron_B3FS-100xP
U1: BME280; BME280_680_BMP280

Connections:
+3V3: C1.1, C2.2, IC1.1, J2.1, PS1.16, R2.1, R7.2, R8.1, R9.1, U1.2, U1.6, U1.8
/AC_L: J1.1, PS1.1
/AC_N: J1.2, PS1.3
/DTR: J2.5, Q3.2, R4.2
/I2C_CLK: IC1.3, R9.2, U1.4
/I2C_SDA: IC1.7, R8.2, U1.3
/IO0: IC1.8, Q3.3, R7.1
/LED: IC1.14, R1.1
/RST: IC1.15, Q1.2, Q2.3, SW1.1
/RTS: J2.6, Q2.2, R3.2, R5.2
/RXD: IC1.11, J2.4
/TXD: IC1.12, J2.3
/WAKE_UP: IC1.17, Q1.3
GNDREF: C1.2, C2.1, D1.1, IC1.9, IC1.13, IC1.18, IC1.19, J2.2, PS1.14, R6.1, SW1.3, U1.1, U1.5, U1.7
unnamed: D1.2, R1.2
unnamed: IC1.2, R2.2
unnamed: IC1.6, R6.2
unnamed: Q1.1, R3.1
unnamed: Q2.1, R4.1
unnamed: Q3.1, R5.1

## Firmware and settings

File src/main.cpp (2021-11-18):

/*
 To flash this, choose the following settings in the Arduino IDE:

     - board:        Generic ESP8266 Board
     - upload speed: 115200
     - reset mode:   "dtr (aka nodemcu)" for mini-reset-circuit
                                     "no dtr (aka ck)" for kevin's circuit

 To ensure EEPROM works:

     - flash frequency: 26Mhz
     - flash size:      2MB (FS: 64KB)

 The remaining things can be left as-is.
*/

#include "cli.h"
#include "config.h"
#include "eeprom.h"
#include "modes/datalogging.h"
#include "modes/push.h"
#include "multimeter.h"
#include "sensor.h"
#include "util.h"
#include "webserver.h"
#include "wifi.h"
#include <LittleFS.h>
#include <xrstf_arduino_util.h>

void runSleepMode(eeprom::data *config, long bootTime) {
	bool sleep = false;

	// if a series name is set, we're in data logging mode
	if (strlen(config->seriesName) > 0) {
		sleep = handleDataLoggingMode(config);
	} else if (config->sleepMinutes > 0) {
		sleep = handlePushMode(config);
	}

	if (sleep) {
		// deduct the time spent from the sleep time
		long delayed     = millis() - bootTime;
		long sleepMillis = (config->sleepMinutes * 60 * 1000) - delayed;

		xrstf::serialPrintf("Nighty night, see you in %ld seconds.\n", (sleepMillis / 1000));

		ESP.deepSleep(sleepMillis * 1000);
	}
}

void setup() {
	long bootTime = millis();

	xrstf::setupLED(LED_PIN);
	multimeter::setup();
	cli::setup();
	eeprom::init();

	LOAD_EEPROM(data);

	if (data.sleepMinutes > 0) {
		runSleepMode(&data, bootTime); // this function _usually_ doesn't return
	}

	wifi::connect(&data);
	webserver::setup();
	webserver::start();

	if (data.enableLED) {
		xrstf::blinkLED(LED_PIN, 3, 200);
	}
}

void loop() {
	if (needsRestart()) {
		ESP.restart();
	}

	cli::handleCommand();
	webserver::handleRequests();
}

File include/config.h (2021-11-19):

#pragma once

// informational purpose only
#define FROY_VERSION "5.0"

// set to 0 if there is no status LED on the board
#define LED_PIN 5

// A0 is the only pin on an ESP-WROOM-02 that has
// an ADC attached, all other pins are digital.
#define BATTERY_PIN A0

// Only some of the variants maintained in https://github.com/esp8266/Arduino/tree/master/variants
// have the correct pinout for an ESP-WROOM-02. To keep the code generic,
// we define our own constants. In the Arduino IDE, just choose "ESP8266 Generic".
#define I2C_SDA_PIN 2  // this is GPIO2, on physical pin 7
#define I2C_SCK_PIN 14 // this is GPIO14, on physical pin 3

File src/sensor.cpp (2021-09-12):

#include "sensor.h"
#include "config.h"
#include <Wire.h>

namespace sensor {
	// Use BME via I2C, so do not give any further arguments.
	Adafruit_BME280 bme280;
	Adafruit_BME680 bme680(&Wire);
	Adafruit_BMP280 bmp280(&Wire);

	const char *typeName(char type) {
		switch (type) {
		case TYPE_BME280:
			return "bme280";
		case TYPE_BME680:
			return "bme680";
		case TYPE_BMP280:
			return "bmp280";
		default:
			return "undefined";
		}
	}

	char decodeTypeName(const char *typeName) {
		if (strcmp(typeName, sensor::typeName(sensor::TYPE_BME280)) == 0) {
			return sensor::TYPE_BME280;
		}

		if (strcmp(typeName, sensor::typeName(sensor::TYPE_BME680)) == 0) {
			return sensor::TYPE_BME680;
		}

		if (strcmp(typeName, sensor::typeName(sensor::TYPE_BMP280)) == 0) {
			return sensor::TYPE_BMP280;
		}

		return 0x0;
	}

	bool test(char address, char type) {
		if (address == 0) {
			return false;
		}

		// manually set up the I2C bus, as we need to
		// override the pin-out to match an ESP-WROOM-02
		Wire.begin(I2C_SDA_PIN, I2C_SCK_PIN);

		switch (type) {
		case TYPE_BME280: {
			if (!bme280.begin(address, &Wire)) {
				return false;
			}

			Adafruit_BME280::sensor_mode operatingMode            = Adafruit_BME280::MODE_FORCED;
			Adafruit_BME280::sensor_sampling tempOversampling     = Adafruit_BME280::SAMPLING_X8;
			Adafruit_BME280::sensor_sampling humidityOversampling = Adafruit_BME280::SAMPLING_X2;
			Adafruit_BME280::sensor_sampling pressureOversampling = Adafruit_BME280::SAMPLING_X4;
			Adafruit_BME280::sensor_filter filtering              = Adafruit_BME280::FILTER_X2;
			Adafruit_BME280::standby_duration standbyTime         = Adafruit_BME280::STANDBY_MS_500;

			bme280.setSampling(operatingMode, tempOversampling, pressureOversampling, humidityOversampling, filtering, standbyTime);
			return true;
		}

		case TYPE_BME680:
			if (!bme680.begin(address)) {
				return false;
			}

			// Set up oversampling and filter initialization
			bme680.setTemperatureOversampling(BME680_OS_8X);
			bme680.setHumidityOversampling(BME680_OS_2X);
			bme680.setPressureOversampling(BME680_OS_4X);
			bme680.setIIRFilterSize(BME680_FILTER_SIZE_3);
			bme680.setGasHeater(320, 150); // 320*C for 150 ms
			return true;

		case TYPE_BMP280: {
			if (!bmp280.begin(address)) {
				return false;
			}

			Adafruit_BMP280::sensor_mode operatingMode            = Adafruit_BMP280::MODE_FORCED;
			Adafruit_BMP280::sensor_sampling tempOversampling     = Adafruit_BMP280::SAMPLING_X8;
			Adafruit_BMP280::sensor_sampling pressureOversampling = Adafruit_BMP280::SAMPLING_X4;
			Adafruit_BMP280::sensor_filter filtering              = Adafruit_BMP280::FILTER_X2;
			Adafruit_BMP280::standby_duration standbyTime         = Adafruit_BMP280::STANDBY_MS_500;

			bmp280.setSampling(operatingMode, tempOversampling, pressureOversampling, filtering, standbyTime);
			return true;
		}

		default:
			return false;
		}
	}

	bool setup(eeprom::data *config) {
		return test(config->sensorAddress, config->sensorType);
	}

	bool read(measurement *m, eeprom::data *config) {
		if (config->sensorType != TYPE_BME280 && config->sensorType != TYPE_BME680 && config->sensorType != TYPE_BMP280) {
			return false;
		}

		m->temperature        = NAN;
		m->humidity           = NAN;
		m->pressure           = NAN;
		m->temperatureRetries = 0;
		m->humidityRetries    = 0;
		m->pressureRetries    = 0;

		char maxRetries = 10;

		// read temperature
		for (char i = 0; i < maxRetries; ++i) {
			switch (config->sensorType) {
			case TYPE_BME280:
				m->temperature = bme280.readTemperature();
				break;
			case TYPE_BME680:
				m->temperature = bme680.readTemperature();
				break;
			case TYPE_BMP280:
				m->temperature = bmp280.readTemperature();
				break;
			}

			if (!isnan(m->temperature)) {
				m->temperature += config->temperatureOffset;
				break;
			}

			m->temperatureRetries++;
			delay(20);
		}

		// read pressure
		for (char i = 0; i < maxRetries; ++i) {
			switch (config->sensorType) {
			case TYPE_BME280:
				m->pressure = bme280.readPressure() / 100.0F;
				break;
			case TYPE_BME680:
				m->pressure = bme680.readPressure() / 100.0F;
				break;
			case TYPE_BMP280:
				m->pressure = bmp280.readPressure() / 100.0F;
				break;
			}

			if (!isnan(m->pressure)) {
				m->pressure += config->pressureOffset;
				break;
			}

			m->pressureRetries++;
			delay(20);
		}

		// read humidity
		if (config->sensorType != TYPE_BMP280) {
			for (char i = 0; i < maxRetries; ++i) {
				switch (config->sensorType) {
				case TYPE_BME280:
					m->humidity = bme280.readHumidity();
					break;
				case TYPE_BME680:
					m->humidity = bme680.readHumidity();
					break;
				}

				if (!isnan(m->humidity)) {
					m->humidity += config->humidityOffset;
					break;
				}

				m->humidityRetries++;
				delay(20);
			}
		}

		return true;
	}
} // namespace sensor

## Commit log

2021-08-21 initial import
    * FroyIndoor 1.2
    * FroyForMen rev 2
    * FroyOutdoor 2.0
    [FroyForMen.kicad_pcb, FroyForMen.sch, FroyIndoor.kicad_pcb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]
2021-08-21 add PCB renders
    [FroyOutdoor.kicad_pcb]
2021-09-12 better HTTP UA, setup BME280 sensors and use forced mode instead of permanent sampling (normal) mode
2021-09-13 Froy Outdoor 2.1, now with transistor controlling sensor and battery measurement
    [FroyOutdoor.kicad_pcb, FroyOutdoor.sch]
2021-09-13 do not make a distinction between has-battery and has-no-battery, likewise for the power transistor
2021-09-24 FroyOutdoor v2.2 - removed power transistor again, used Omron button
    [FroyOutdoor.kicad_pcb, FroyOutdoor.sch]
2021-09-24 remove concept of power transistor from the codebase
2021-10-04 FroyForMen v1.3 - removed power transistor, use Omron button
    [FroyForMen.kicad_pcb, FroyForMen.sch]
2021-10-09 fix a couple of typos
    [cli.cpp, push.cpp, webserver.cpp]
2021-10-09 FroyOutdoor v2.3 - expose I2C SDA/SCL pins to make it easy to reuse the board for quick experiments with other breakout boards
    [FroyOutdoor.kicad_pcb, FroyOutdoor.sch]
2021-10-10 FroyIndoor v1.2.1 - fix silk screen for the I2C pins, use more common resistor values
    [FroyIndoor.kicad_pcb, FroyIndoor.sch]
2021-10-17 save bytes by making the push payload use cryptic short key names
    [push.cpp, webserver.cpp]
2021-10-23 add FroyLogger, with a realtime clock and much more exposed GPIO pins to serve as a nice WiFi-enabled datalogger
    [FroyLogger.kicad_pcb, FroyLogger.sch]
2021-11-14 FroyLogger 3.0.1, better crystal footprint
    [FroyLogger.kicad_pcb, FroyLogger.sch]
2021-11-17 fix junk output at dumping a time series
    [datalogger.cpp]
